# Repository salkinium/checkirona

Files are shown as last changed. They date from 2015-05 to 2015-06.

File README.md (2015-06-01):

# Checkirona: iPhone Connector Short-Circuit Tester

[Corona][corona] uses the 30pin iPhone connector to communicate with everything.

This simple project uses an STM32F4 Discovery with a custom connector PCB board to test all 30 connections for a short circuit and displays it as an adjacency matrix and as a flattened connector view.

You must connect a USB-to-Serial connector and open a terminal using picocom:

	$ picocom --imap lfcrlf -b 115200 /dev/tty.usbserial-*

The output for a functioning connector looks like this:

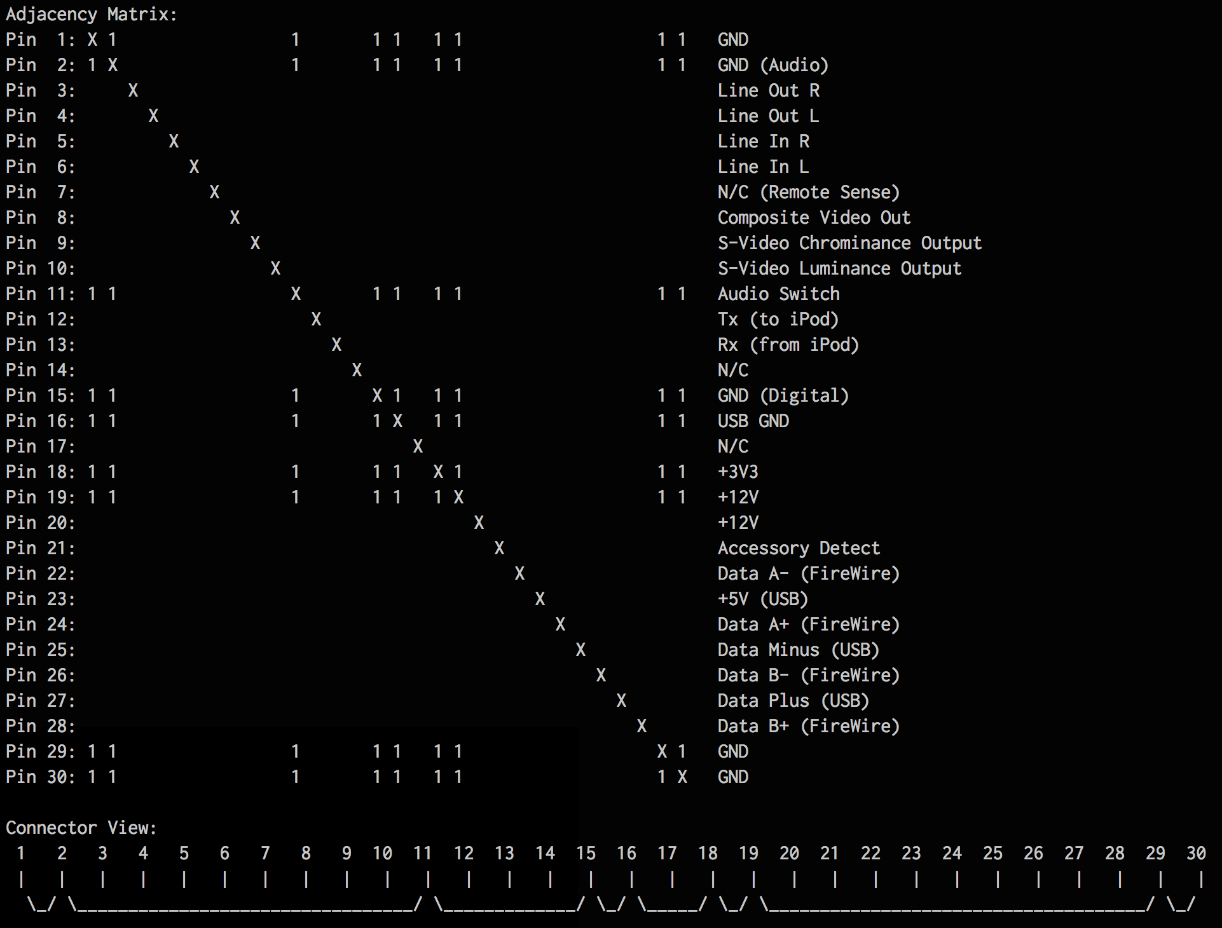
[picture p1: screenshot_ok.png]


The output for a broken connector looks like this:

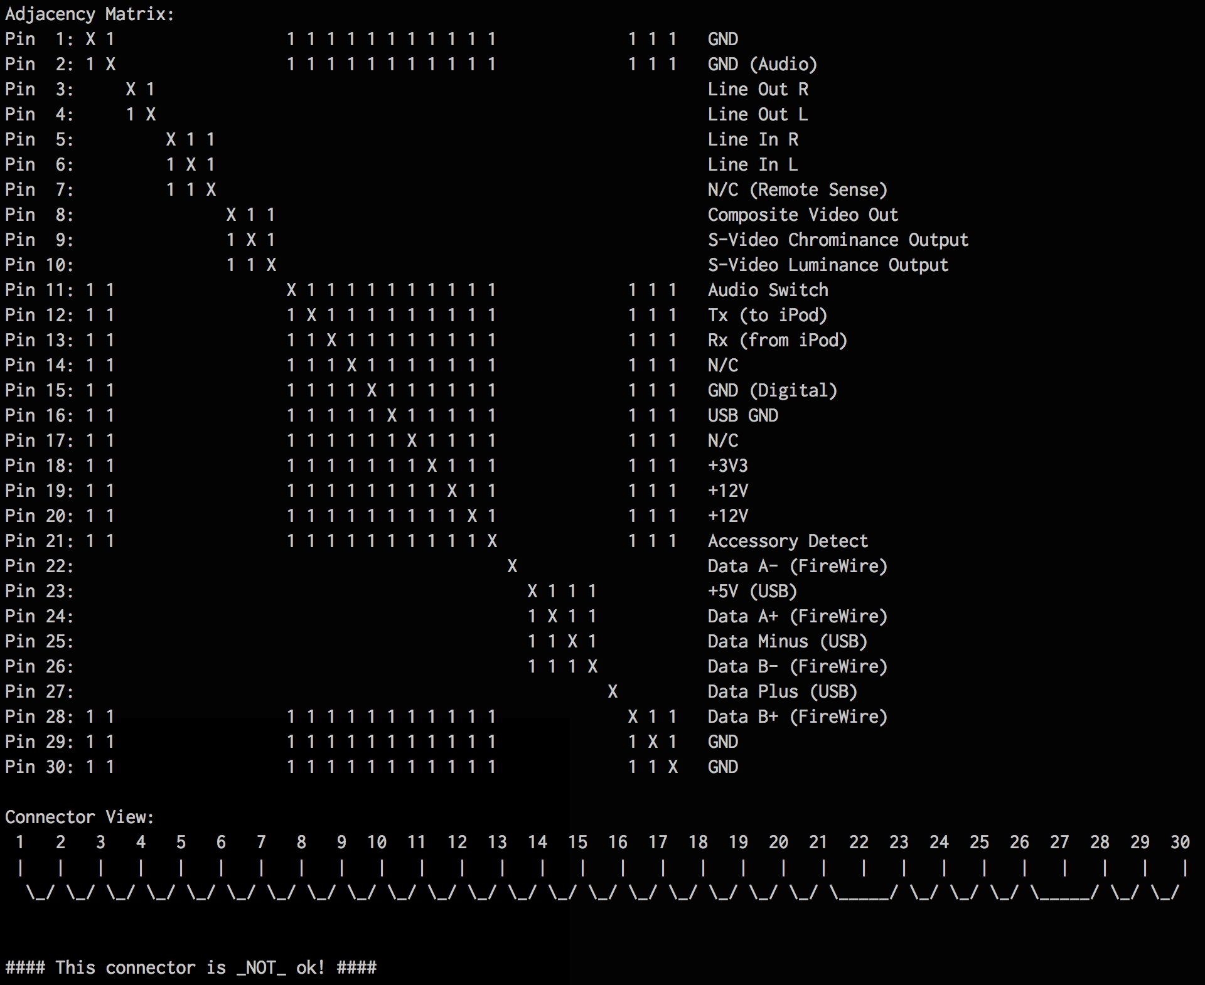
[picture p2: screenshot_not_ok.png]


This project was designed and manufactured at [The Media Computing Group][i10].

## Organization

This repository is organized as follows:

-	*pcb* contains the PCB schematics and layouts,
- 	*src* contains the application code for the tester, and
-	*xpcc* contains the git submodule for the xpcc.io microcontroller framework.

All hardware and embedded software was designed by [Niklas Hauser][hauser].

## Building from source

The sources are compiled using the [xpcc C++ Microcontroller Framework][xpcc].

#### Setup your environment

xpcc is provided as a git submodule, to use it run this in the root `checkirona/` directory:

	$ git submodule init
	$ git submodule update

We configured a [headless virtual machine][rca-vm] for VirtualBox (size: ~1.2GB), which
is managed using Vagrant and contains all software required for compiling xpcc.

Install [VirtualBox][] and [Vagrant][] and use the VM like this:

    $ vagrant up
    $ vagrant ssh

#### Compile and Program

Enter the `src` directory

	$ cd /vagrant/src

To compile, execute:

	$ scons

To flash the binary onto the microcontroller, execute:

	$ scons program

[i10]: http://hci.rwth-aachen.de
[corona]: http://hci.rwth-aachen.de/corona
[hauser]: http://hci.rwth-aachen.de/hauser

[xpcc]: http://xpcc.io
[virtualbox]: https://www.virtualbox.org/wiki/Downloads
[vagrant]: http://www.vagrantup.com/downloads.html
[rca-vm]: https://github.com/roboterclubaachen/rca-vm

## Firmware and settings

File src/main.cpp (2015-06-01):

// coding: utf-8
// ----------------------------------------------------------------------------

#include "hardware.hpp"

using namespace Hardware;

void
print30pins(uint8_t id, uint32_t value)
{
	for (int ii=0; ii < NumberOfPins; ii++)
	{
		if (id == ii) {
			serial << "X ";
		} else {
			serial << ((value & (1 << ii)) ? "1 " : "  ");
		}
	}
}

void
printPin(uint8_t id)
{
	serial.printf("Pin %2d: ", (id+1));
	print30pins(id, connectionMatrix[id]);
	serial << "  " << gpios[id].name << "\n";

	// print30pins(id, down);
}

void
printConnector()
{
	for (int ii=0; ii < NumberOfPins; ii++)
	{
		serial.printf("%2d  ", ii+1);
	}
	serial << "\n";
	for (int ii=0; ii < NumberOfPins; ii++)
	{
		serial << " |  ";
	}
	serial << "\n";
}

constexpr uint8_t lines = 30;
constexpr uint8_t colums = 4*NumberOfPins;
uint32_t flattened[lines];
char scratch[lines][colums+1];
bool too_many = false;

void
printIntoScratch(uint8_t line, uint8_t pos, const char *string)
{
	while(pos < colums and *string != '\0')
	{
		scratch[line][pos++] = *string++;
	}
}

void
printConnection(uint8_t from, uint8_t to)
{
	uint32_t flat = 0;
	for (int ii=from+1; ii <= to; ii++)
	{
		flat |= (1 << ii);
	}
	int line = 0;
	while (line < lines and flattened[line] & flat) {
		line++;
	}
	if (line >= lines) {
		too_many = true;
		return;
	}
	flattened[line] |= flat;

	printIntoScratch(line, from*4+2, "\\_");
	for (int ii=from+1; ii < to; ii++)
	{
		printIntoScratch(line, ii*4, "____");
	}
	printIntoScratch(line, to*4, "/");
}

void
printAllConnections()
{
	for (int ii=0; ii < lines; ii++)
	{
		if (flattened[ii])
		{
			serial << scratch[ii] << "\n";
		}
	}

	if (too_many)
		serial << "\nThere were more connections than could be visualized!";
}

// ----------------------------------------------------------------------------
int main(void)
{
	systemClock::enable();
	xpcc::cortex::SysTickTimer::enable();

	GpioOutputA2::connect(Uart::Tx);
	Uart::initialize<systemClock, Uart::B115200>(10);

	LedOrange::setOutput(xpcc::Gpio::Low);
	LedRed::setOutput(xpcc::Gpio::Low);
	LedBlue::setOutput(xpcc::Gpio::Low);
	LedGreen::setOutput(xpcc::Gpio::Low);

	LedGreen::setOutput(xpcc::Gpio::High);

	std::memset(&flattened, 0, lines * 4);
	// fill with spaces
	std::memset(scratch, ' ', lines * (colums+1));
	// but the last one must be zero
	for (int ii=0; ii < lines; ii++)
	{
		scratch[ii][colums] = 0;
	}

	for (NamedGpio gpio : gpios)
	{
		gpio.gpio->setInput(Gpio::InputType::Floating);
	}

	for (int ii=0; ii < NumberOfPins; ii++)
	{
		LedOrange::toggle();
		gpios[ii].gpio->setOutput(xpcc::Gpio::High);

		uint32_t valueUp = 0;
		for (int jj=0; jj < NumberOfPins; jj++)
		{
			if (jj == ii) continue;

			gpios[jj].gpio->configure(Gpio::InputType::PullDown);
			xpcc::delayMicroseconds(400);
			// if pin j is high, it is connected to pin i
			valueUp |= ((gpios[jj].gpio->read() ? 1 : 0) << jj);
			gpios[jj].gpio->configure(Gpio::InputType::Floating);
		}

		gpios[ii].gpio->setOutput(xpcc::Gpio::Low);

		uint32_t valueDown = 0;
		for (int jj=0; jj < NumberOfPins; jj++)
		{
			if (jj == ii) continue;

			gpios[jj].gpio->configure(Gpio::InputType::PullUp);
			xpcc::delayMicroseconds(400);
			// if pin j is high, it is _not_ connected to pin i
			valueDown |= ((gpios[jj].gpio->read() ? 0 : 1) << jj);
			gpios[jj].gpio->configure(Gpio::InputType::Floating);
		}

		gpios[ii].gpio->setInput(Gpio::InputType::Floating);

		connectionMatrix[ii] = valueDown & valueUp;
	}

	LedOrange::reset();
	LedGreen::reset();

	// ANALYSIS

	// Magic ANSI escape codes clear the screen
	serial << "\033[2J\033[1;1H";

	uint32_t allConnections = 0;
	// this magic number contains the desired ("vetted") connections.
	static constexpr uint32_t correctConnections = 0b110000000001101100010000000011;

	// print connection matrix
	serial << "Adjacency Matrix:\n";
	for (int ii=0; ii < NumberOfPins; ii++)
	{
		allConnections |= (connectionMatrix[ii] & ((1 << ii) - 1));
		printPin(ii);
	}

	// print flattened connectors
	serial << "\nConnector View:\n";
	printConnector();

	for (int ii=0; ii < NumberOfPins; ii++)
	{
		if (allConnections & (1 << ii))
		{
			for (int jj=ii+1; jj < NumberOfPins; jj++)
			{
				if (allConnections & (1 << jj)) {
					printConnection(ii, jj);
					ii = jj-1;
					break;
				}
			}
		}
	}

	printAllConnections();

	bool ok = (allConnections == correctConnections);

	if (ok)	{
		LedBlue::set();
		serial << "\n\nThis connector is ok!" << xpcc::endl;
	} else {
		LedRed::set();
		serial << "\n\n#### This connector is _NOT_ ok! ####" << xpcc::endl;
	}


	while (1)
		;

	return 0;
}

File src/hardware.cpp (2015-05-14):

// coding: utf-8

#include "hardware.hpp"

// --- --- --- --- --- --- --- Communication  --- --- --- --- --- --- ---
xpcc::IODeviceWrapper<Hardware::Uart, xpcc::IOBuffer::BlockIfFull> outputDevice;
xpcc::IOStream Hardware::serial(outputDevice);

using namespace xpcc::stm32;

// a list of all possible Gpios
// Only those that are in the `gpios` array, will actually be linked into the code!

// --- --- --- --- --- --- --- ---  GPIO  --- --- --- --- --- --- --- ---

// Port A
VirtualGpioWrapper<GpioA0> gpioA0;
VirtualGpioWrapper<GpioA1> gpioA1;
VirtualGpioWrapper<GpioA2> gpioA2;
VirtualGpioWrapper<GpioA3> gpioA3;
VirtualGpioWrapper<GpioA4> gpioA4;
VirtualGpioWrapper<GpioA5> gpioA5;
VirtualGpioWrapper<GpioA6> gpioA6;
VirtualGpioWrapper<GpioA7> gpioA7;
VirtualGpioWrapper<GpioA8> gpioA8;
VirtualGpioWrapper<GpioA9> gpioA9;
VirtualGpioWrapper<GpioA10> gpioA10;
VirtualGpioWrapper<GpioA11> gpioA11;
VirtualGpioWrapper<GpioA12> gpioA12;
VirtualGpioWrapper<GpioA13> gpioA13;
VirtualGpioWrapper<GpioA14> gpioA14;
VirtualGpioWrapper<GpioA15> gpioA15;

// Port B
VirtualGpioWrapper<GpioB0> gpioB0;
VirtualGpioWrapper<GpioB1> gpioB1;
VirtualGpioWrapper<GpioB2> gpioB2;
VirtualGpioWrapper<GpioB3> gpioB3;
VirtualGpioWrapper<GpioB4> gpioB4;
VirtualGpioWrapper<GpioB5> gpioB5;
VirtualGpioWrapper<GpioB6> gpioB6;
VirtualGpioWrapper<GpioB7> gpioB7;
VirtualGpioWrapper<GpioB8> gpioB8;
VirtualGpioWrapper<GpioB9> gpioB9;
VirtualGpioWrapper<GpioB10> gpioB10;
VirtualGpioWrapper<GpioB11> gpioB11;
VirtualGpioWrapper<GpioB12> gpioB12;
VirtualGpioWrapper<GpioB13> gpioB13;
VirtualGpioWrapper<GpioB14> gpioB14;
VirtualGpioWrapper<GpioB15> gpioB15;

// Port C
VirtualGpioWrapper<GpioC0> gpioC0;
VirtualGpioWrapper<GpioC1> gpioC1;
VirtualGpioWrapper<GpioC2> gpioC2;
VirtualGpioWrapper<GpioC3> gpioC3;
VirtualGpioWrapper<GpioC4> gpioC4;
VirtualGpioWrapper<GpioC5> gpioC5;
VirtualGpioWrapper<GpioC6> gpioC6;
VirtualGpioWrapper<GpioC7> gpioC7;
VirtualGpioWrapper<GpioC8> gpioC8;
VirtualGpioWrapper<GpioC9> gpioC9;
VirtualGpioWrapper<GpioC10> gpioC10;
VirtualGpioWrapper<GpioC11> gpioC11;
VirtualGpioWrapper<GpioC12> gpioC12;
VirtualGpioWrapper<GpioC13> gpioC13;
VirtualGpioWrapper<GpioC14> gpioC14;
VirtualGpioWrapper<GpioC15> gpioC15;

// Port D
VirtualGpioWrapper<GpioD0> gpioD0;
VirtualGpioWrapper<GpioD1> gpioD1;
VirtualGpioWrapper<GpioD2> gpioD2;
VirtualGpioWrapper<GpioD3> gpioD3;
VirtualGpioWrapper<GpioD4> gpioD4;
VirtualGpioWrapper<GpioD5> gpioD5;
VirtualGpioWrapper<GpioD6> gpioD6;
VirtualGpioWrapper<GpioD7> gpioD7;
VirtualGpioWrapper<GpioD8> gpioD8;
VirtualGpioWrapper<GpioD9> gpioD9;
VirtualGpioWrapper<GpioD10> gpioD10;
VirtualGpioWrapper<GpioD11> gpioD11;
VirtualGpioWrapper<GpioD12> gpioD12;
VirtualGpioWrapper<GpioD13> gpioD13;
VirtualGpioWrapper<GpioD14> gpioD14;
VirtualGpioWrapper<GpioD15> gpioD15;

// Port E
VirtualGpioWrapper<GpioE0> gpioE0;
VirtualGpioWrapper<GpioE1> gpioE1;
VirtualGpioWrapper<GpioE2> gpioE2;
VirtualGpioWrapper<GpioE3> gpioE3;
VirtualGpioWrapper<GpioE4> gpioE4;
VirtualGpioWrapper<GpioE5> gpioE5;
VirtualGpioWrapper<GpioE6> gpioE6;
VirtualGpioWrapper<GpioE7> gpioE7;
VirtualGpioWrapper<GpioE8> gpioE8;
VirtualGpioWrapper<GpioE9> gpioE9;
VirtualGpioWrapper<GpioE10> gpioE10;
VirtualGpioWrapper<GpioE11> gpioE11;
VirtualGpioWrapper<GpioE12> gpioE12;
VirtualGpioWrapper<GpioE13> gpioE13;
VirtualGpioWrapper<GpioE14> gpioE14;
VirtualGpioWrapper<GpioE15> gpioE15;

// Port H
//VirtualGpioWrapper<GpioH0> gpioH0;
//VirtualGpioWrapper<GpioH1> gpioH1;

namespace Hardware
{

// initialize the array of GPIOs
// we only construct those who are FreeIO on the STM32F407 Discovery Board
// others are null pointers and therefore invalid
NamedGpio const gpios[NumberOfPins] =
{
	{&gpioD3, "GND"},
	{&gpioD6, "GND (Audio)"},
	{&gpioD7, "Line Out R"},
	{&gpioB5, "Line Out L"},
	{&gpioB4, "Line In R"},

	{&gpioB7, "Line In L"},
	{&gpioB8, "N/C (Remote Sense)"},
	{&gpioE2, "Composite Video Out"},
	{&gpioD2, "S-Video Chrominance Output"},
	{&gpioC11, "S-Video Luminance Output"},

	{&gpioA15, "Audio Switch"},
	{&gpioA8, "Tx (to iPod)"},
	{&gpioC8, "Rx (from iPod)"},
	{&gpioC9, "N/C"},
	{&gpioC6, "GND (Digital)"},

	{&gpioD11, "USB GND"},
	{&gpioD10, "N/C"},
	{&gpioB15, "+3V3"},
	{&gpioB13, "+12V"},
	{&gpioB14, "+12V"},

	{&gpioB11, "Accessory Detect"},
	{&gpioB12, "Data A- (FireWire)"},
	{&gpioE7, "+5V (USB)"},
	{&gpioE10, "Data A+ (FireWire)"},
	{&gpioE9, "Data Minus (USB)"},

	{&gpioE12, "Data B- (FireWire)"},
	{&gpioE11, "Data Plus (USB)"},
	{&gpioE14, "Data B+ (FireWire)"},
	{&gpioE13, "GND"},
	{&gpioE15, "GND"},
};

}	// namespace Hardware

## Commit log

2015-05-11 Add connector pcb.
    [stm32f4_adapter.brd, stm32f4_adapter.sch]
2015-05-11 Add compilable software.
    [project.cfg]
2015-05-13 Increase serial output buffer. Not necessary, just because we can!
    [project.cfg]
2015-05-13 Add printing of adjacency matrix and connector view.
2015-05-14 Move pin E3 to E2, because E3 is used by CS_I2C/SPI!
    For Rev. 2. the STM32F4 Discovery datasheet is lying!
    [stm32f4_adapter.brd, stm32f4_adapter.sch]
2015-05-16 Squash all connections into one line on connector view.
2015-06-01 Add magic number for correct connections and better screenshots.
    [main.cpp]
2015-06-01 More accurate connector view.
